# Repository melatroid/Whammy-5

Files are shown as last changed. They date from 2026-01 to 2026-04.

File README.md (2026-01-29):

# --Whammy 5 - NEO Mod--
This is a Modification for the Digitech Whammy 5- <br>
You get full Access to Midi Functions, with a Microcontroller inside. <br>
Im Working on nice Software for Whammy, that you can easly update. <br>
You need all modifications to use the featueres. Good Luck <br>

# Basic Version for Free
Software is for Free, to use all Features buy Pro Version

# Pro & Flashing Tool for 2040 Zero here...
<div align="left">
  <a href="https://www.nexosoft-engineering.de/neo/index.html">Pro Version & Flashing</a>
</div>

<h1>
!!! Attention !!!<br>
This Modification could brick your Device!
You lose your manufacturer's warranty.
<h1>

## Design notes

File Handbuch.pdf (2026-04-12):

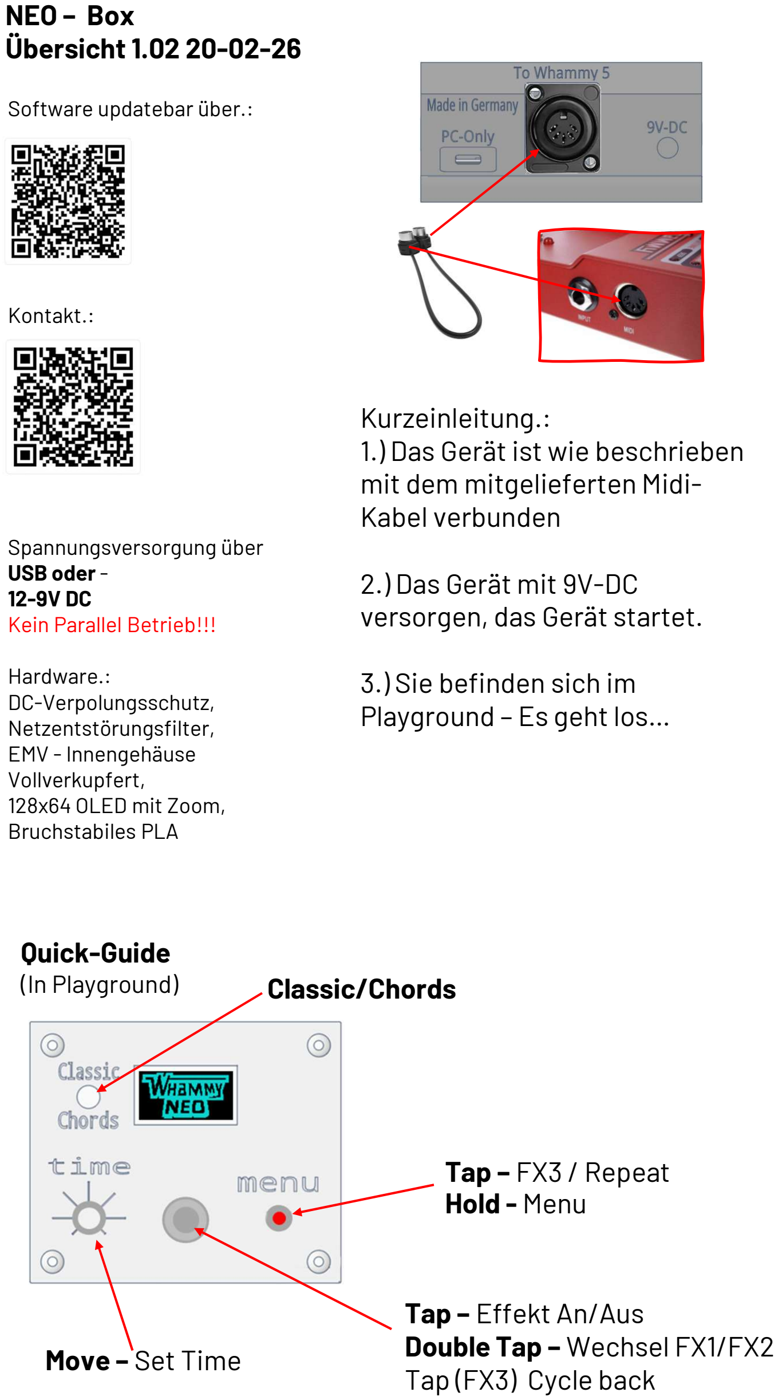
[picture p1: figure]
NEO – Box Übersicht 1.02 20-02-26; Software updatebar über.:; Kontakt.:; Spannungsversorgung über USB oder- 12-9V DC Kein Parallel Betrieb!!!; Hardware.: DC-Verpolungsschutz, Netzentstörungsfilter, EMV - Innengehäuse Vollverkupfert, 128x64 OLED mit Zoom, Bruchstabiles PLA; Quick-Guide (In Playground); Tap – Effekt An/Aus Double Tap – Wechsel FX1/FX2 Tap (FX3) Cycle back; Tap – FX3 / Repeat Hold - Menu; Classic/Chords; Move – Set Time; Kurzeinleitung.: 1.) Das Gerät ist wie beschrieben mit dem mitgelieferten Midi- Kabel verbunden; 2.) Das Gerät mit 9V-DC versorgen, das Gerät startet.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

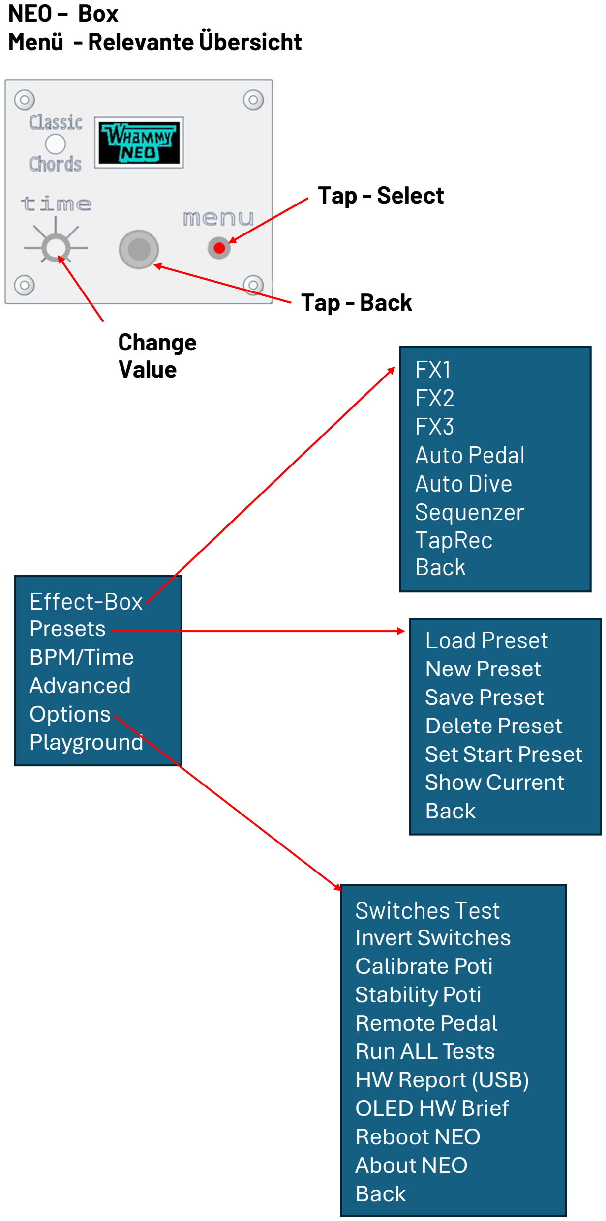
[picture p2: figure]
Menü - Relevante Übersicht; Effect-Box Presets BPM/Time Advanced Options Playground; Tap - Select; Switches Test Invert Switches Calibrate Poti Stability Poti Remote Pedal Run ALL Tests HW Report (USB) OLED HW Brief Reboot NEO About NEO Back; Load Preset New Preset Save Preset Delete Preset Set Start Preset Show Current Back; Tap - Back; FX1 FX2 FX3 Auto Pedal Auto Dive Sequenzer TapRec Back; Change Value

Effekt-Box

FX1
FX2
FX3

Auto Pedal
Auto Dive
Sequenzer
TapRec
Back

Festlegen von FX 1, FX2 und FX3

Grafikeditoren für Kurven etc.
Auch hier nach dem editieren speichern!

Zum Festlegen der FX1–3 sind Angaben zum gewünschten Effekt nötig. Diesen Effekt kennen Sie in der Regel bereits im Vorfeld, da Sie offensichtlich Besitzer und Spieler eines Whammy 5 sind. Man kann Gitarristen an dieser Stelle vorwerfen, dass sie ihren Lieblingseffekt schon länger haben und ihn nur weiter aufpeppen wollen. Falls dem nicht so ist, sollten Sie sich darum bemühen, eine klare Vorstellung davon zu entwickeln, wie es klingen soll.
Sie werden mit der NEO-Box nicht glücklich, wenn Sie sie als Findungswerkzeug für gute Sounds benutzen wollen. Umso nützlicher ist sie, wenn Sie bereits eine Vorstellung davon haben, wie es klingen soll.
Es wird in die linke und rechte Effektsektion des Whammy 5 unterteilt: Harmony- und Whammy-Effekte. Hier muss zunächst das grundlegende Verhalten eingestellt werden. Grundsätzlich ist der FX3 der Taste L (menu) vorbehalten. Sie ist für die Auto-Pedal-Funktionen vorgesehen, die ausgewählt und anschließend im entsprechenden Editor grafisch bearbeitet werden können.

Nach dem editieren unbedingt das Preset (Save Preset) überschrieben!

FX-Menü (FX 1 / FX 2 / FX 3) • | Type – Classic oder Chords • | Name/Mode – Whammy oder Harmony • | Behavior – Original - Momentary - Time Holding - Shutter Gate - Step Sequenzer - Tap Rec. • | Pedal Position (nur FX1/FX2)-

Whammy – ▲ 2 OCT - ▲ OCT - ▲ 5TH - ▲ 4TH - ▼ 2ND - ▼ 4TH - ▼ 5TH - ▼ OCT - ▼ 2 OCT

Harmony – 2ND/3RD - b3RD/3RD - 3RD/4TH - 4TH/5TH - 5TH/6TH - 5TH/7TH - 4TH/3RD - 5TH/4TH -

▲OCT/OCT▼

Grafik Editoren

FX1
FX2
FX3

Auto Pedal
Auto Dive
Sequenzer
TapRec
Back

Über die Effekt-Box sind die Editoren zugänglich. Dieses Skript soll nur eine kurze Einführung geben.

Wenn Sie sich in bereits in einem der Editoren befinden, kommen Sie über hold der L-Taste in das Menu des jeweiligen Editors.

M-Taste

Pedal und Dive bieten Rekord Funktionen mit der Pedal-Kurven über das Potentiometer geschrieben werden können. (DAW-Benutzer kennen
diesen Mechanismus des Schreibens und Veränderns von Musikdaten bereits)
Die aufgenommene Kurve kann, wie bei einem grafischen Equalizer verändert werden, wobei die Glockenbreite über L eingestellt wird. Es gibt hier eine umfangreiche Spielwiese an Tools im Menu, um zu experimentieren.

Bei TapRec wird die Tastensequenz von M aufgenommen. Sequenzer bildet die Ausnahme, dafür können hier Steps komfortabel über T gebaut werden und mit dem Poti auf die gewünschte Position gesetzt werden.

Die Editoren bieten eine Save Funktion, die mehr ermöglicht als die reinen Presets.

Einige Editoren haben in eingeschränkter Wiedergabe-Qualität, einen Play Modus, um die Bearbeitung direkt zu testen.

L-Taste – Select
Hold - Menu

Change
Value

Erklärungen
Presets legen das Startverhalten der NEO-Box für FX1/FX2/FX3 fest. NEO-Box speichert nicht automatisch, um Fehlerhafte-Änderungen über einen Neustart wiederrufbar zu machen. Das Start-preset ist Default

Advanced enthält Systemeigenschaften die direkte Auswirkungen, auf das Verhalten der Fußschalter hat.
Es wird wärmstens empfohlen nichts zu verändern. • AutoByp:ON|OFF (Auto-Bypass aktivieren/deaktivieren) • Delay: <0..30000>ms (Bypass-Delay) • TapHold: <20..60000>ms (Tap/Hold Zeit) • HoldMin: <50..60000>ms • HoldMax: <50..60000>ms • Smooth: <0..100> (Poti-Glättung) • Deb: <10..250>ms (Button Debounce) • Samp: <10..100>ms (Auto Sample) • Max: <5000..600000>ms (Auto MaxLen)
Options enthält Einstellungen, Kalibrierungen und Tests. • | Switches Test (Schaltertest) • | Invert Switches: (Untermenü zum Invertieren von Schaltern ) • | Calibrate Poti: (Potentiometer kalibrieren) • | Stability Poti: (Stabilitätstest Poti) • | Remote Pedal: (Remote-Pedal Test (AutoPedal/AutoDive)) • | Run ALL Tests: (Alle Tests ausführen ) • | HW Report (USB) (Hardware-Report via USB/Serial ausgeben ) • | OLED HW Brief: (OLED Kurzreport) • | Reboot NEO (Neustart) • | About NEO: Info-Screen
BPM/Time (Experimentell) • | Tap BPM- (BPM per Tap ermitteln) • | Set BPM- (BPM per Poti setzen) • | Show BPM- (aktuellen BPM-Wert ) • | Reset- (120 BPM)

NEO – FAQ • Beim Deaktivieren des Effekts, wird der

darunterliegende aktiv gesetzt, stimmt das?

Ja, Es ist von DT technisch so umgesetzt. Und nicht anders möglich • Es kommt zu ungleichmäßigen Schaltverhalten im

ShutterGate, TapRec, Sequenzer

Das Gerät zuvor im Modus länger laufen lassen, es stabilisiert sich. Zuvor Speichern, alles neustarten. • Das Gerät fordert mich auf einen Code einzugeben.

Kontakt über E-Mail herstellen. • Das Whammy schaltet/klickt laut.

Beim Wh5 hat DT -Relais verbaut, die als TrueBypass dienen. Relais sind mechanische Bauteile und unterliegen einer natürlichen Haltbarkeit. Schaltvorgänge nicht strapazieren. • Das Gerät geht nach Verbindung mit dem 9V Adapter

nicht an.

9V Spannungsversorgungen gibt es in zwei Ausführungen. Die NEO-Box wurde für die gängige Pedalboard 9DC ausgelegt.

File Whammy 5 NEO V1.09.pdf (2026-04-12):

Whammy 5 – NEO – Version 1.09 By melatroid

melatroid@gmail.com

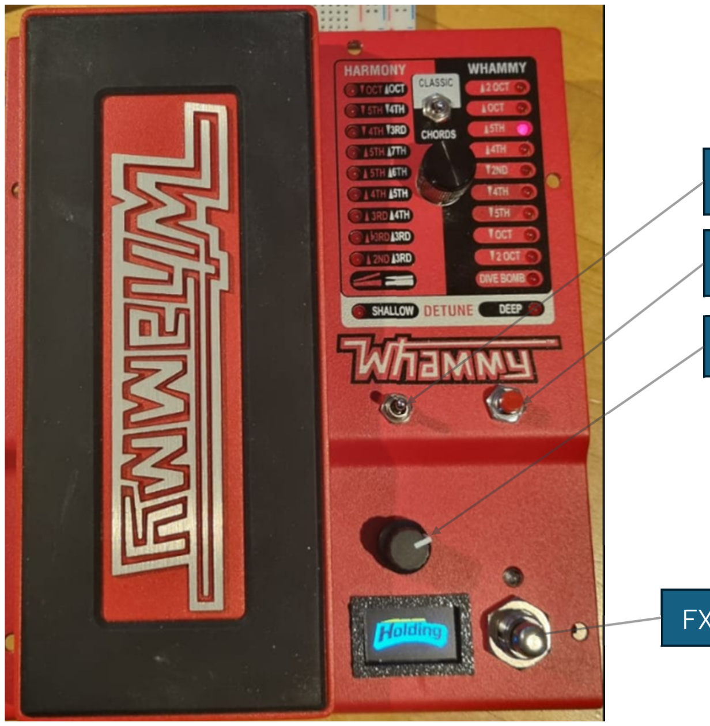
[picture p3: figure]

FX 1 - 2

Time/Position

FX 3 /
Menü

Calibration

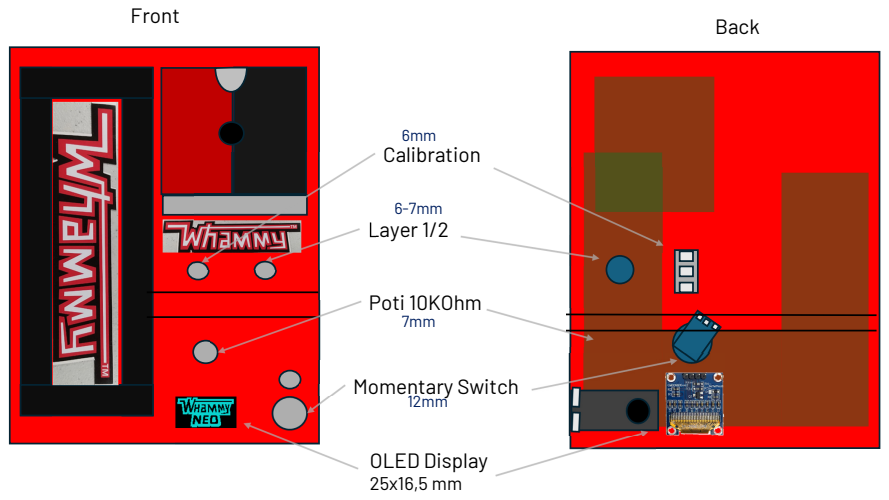
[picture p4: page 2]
Front; Back; Poti 10KOhm 7mm; Momentary Switch 12mm; Layer 1/2; OLED Display 25x16,5 mm; Calibration

### Drills

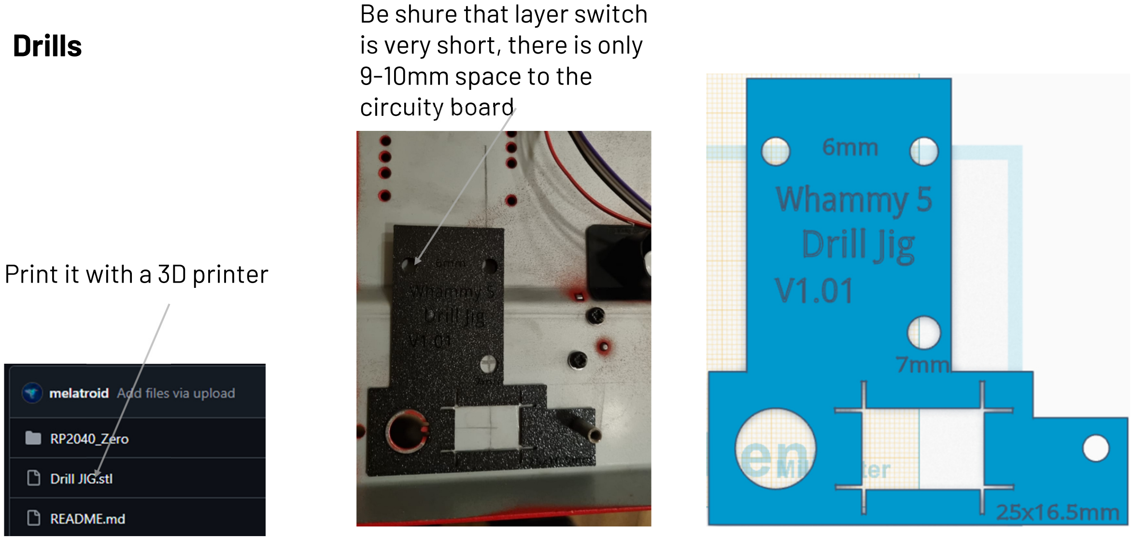
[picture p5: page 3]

Print it with a 3D printer

Be shure that layer switch is very short, there is only 9-10mm space to the
circuity board

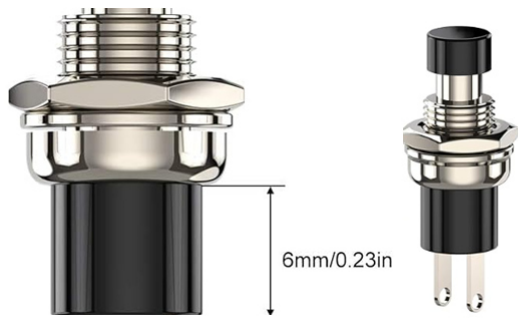
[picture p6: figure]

ELKO/Ceramic
Condenser

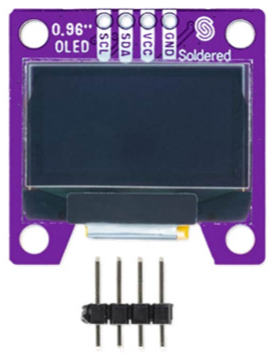
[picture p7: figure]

Raspberry Pi
2040 Zero

10KΩ

SPST, NO,
Momentary !!!

### Parts

220Ω 2x

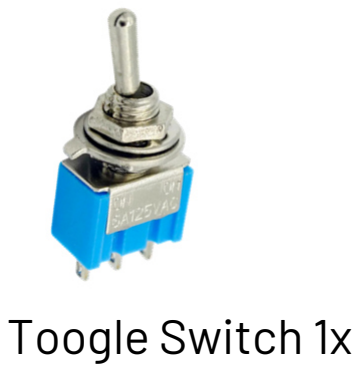
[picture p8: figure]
Toogle Switch 1x

Calibration (3 Way)

DC/DC
LM2596

uF

### 47 nF

B0505S-1W

https://tweakable-parts.com/en/footswitches/175-spst-momentary-switch.html
Normally Open! → PBS 24B 4L
Long Version!

SSD1306 OR
SSD1315
O-LED
I²C !!!

!!!
SPST, NO, 1x
Layer 1/2 Momentary !!!

### Tools

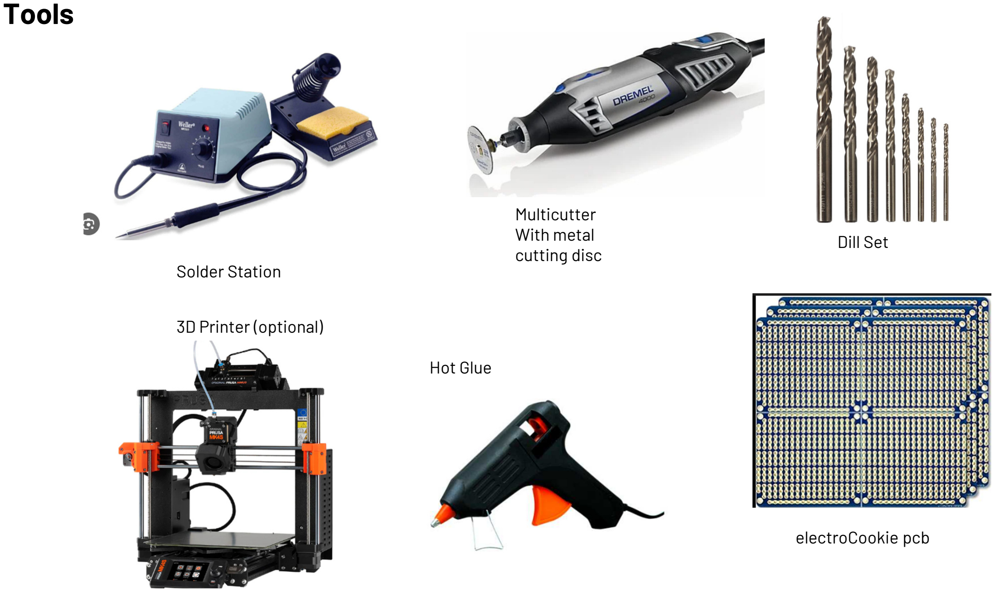
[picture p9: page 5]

Solder Station

Multicutter
With metal
cutting disc

Dill Set

3D Printer (optional)

Hot Glue

electroCookie pcb

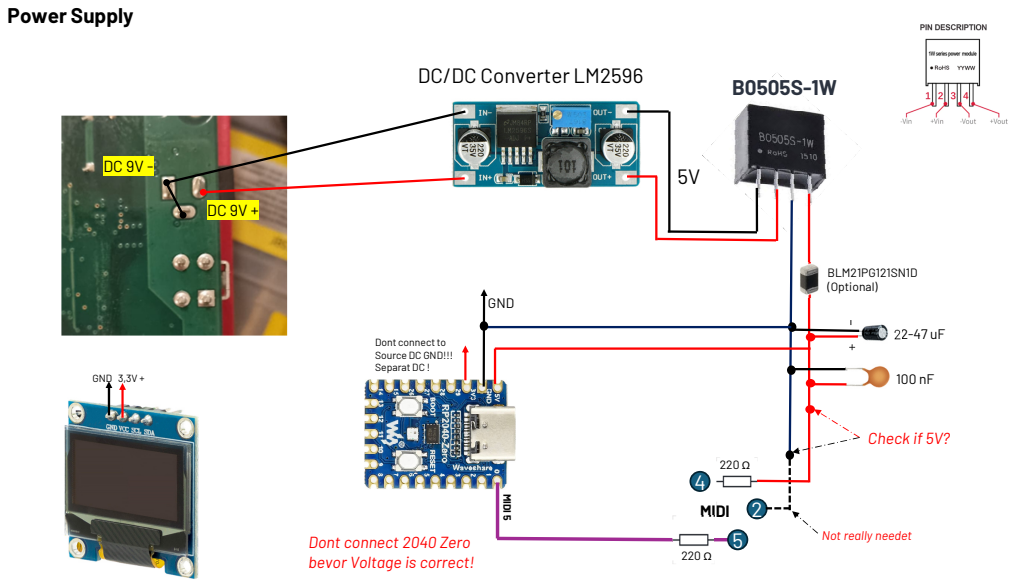
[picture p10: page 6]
Power Supply; MIDI 5; MIDI; BLM21PG121SN1D (Optional); Check if 5V?; 3,3V +GND; GND

DC/DC Converter LM2596

Dont connect to
Source DC GND!!!
Separat DC !

Not really needet

Dont connect 2040 Zero
bevor Voltage is correct!

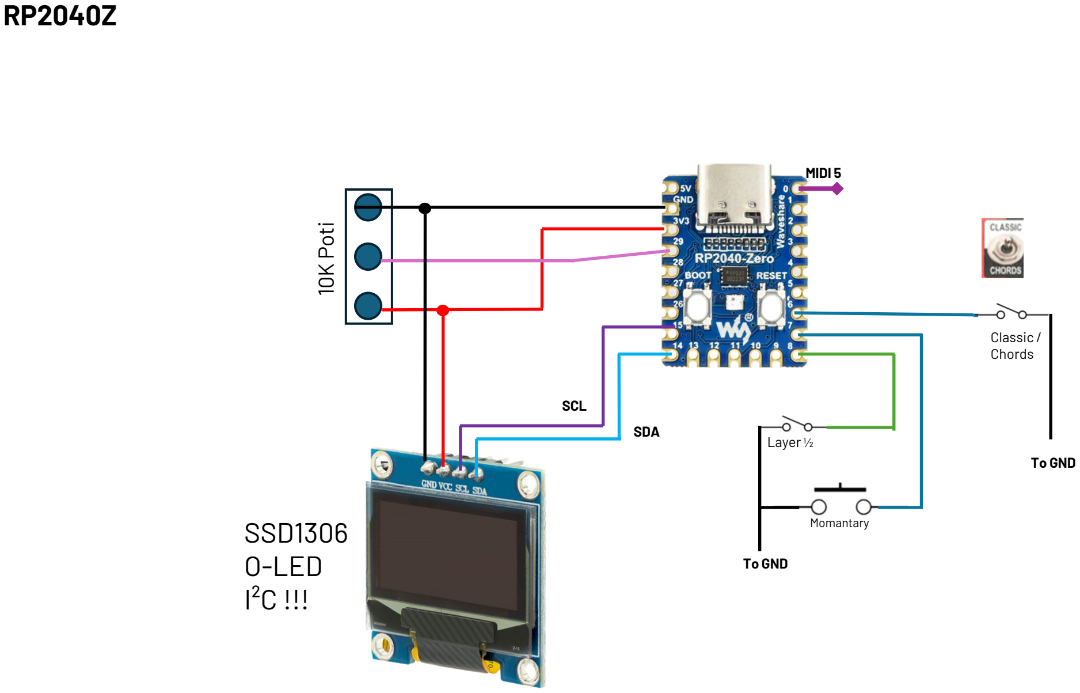
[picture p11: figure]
10K Poti; Momantary; MIDI 5; Layer ½; SDA; SCL; SSD1306 O-LED I²C !!!; To GND; Classic / Chords

### Inside

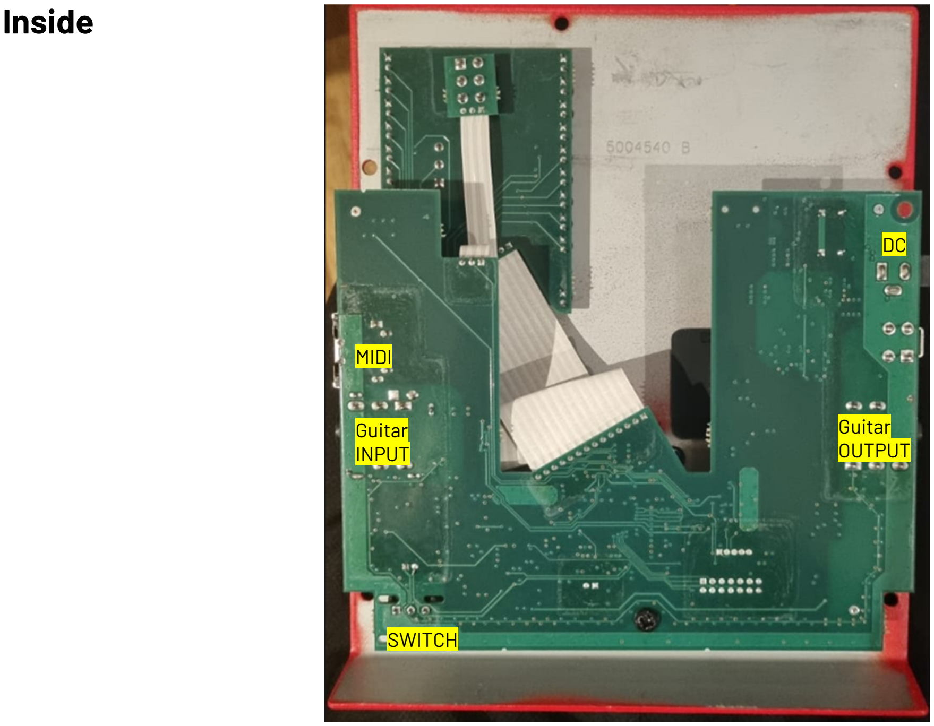
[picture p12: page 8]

Guitar
INPUT

Guitar
OUTPUT

DC

MIDI

SWITCH

### Midi

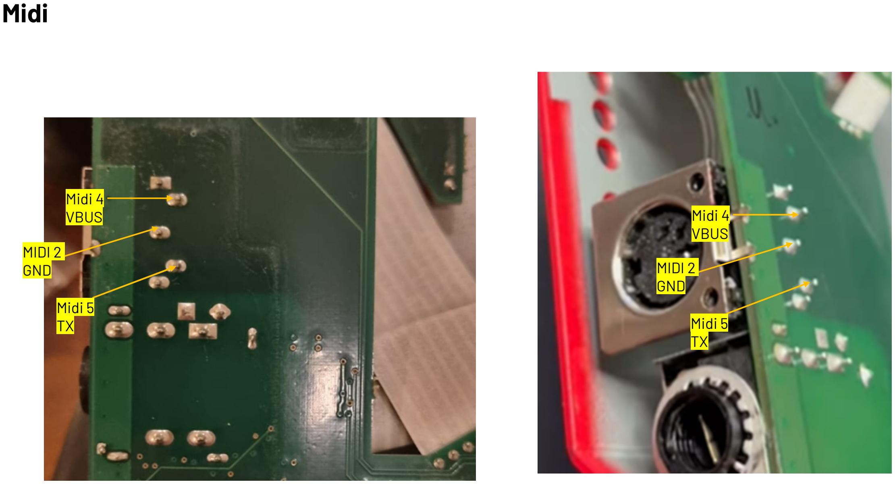
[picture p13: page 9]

Midi 4
VBUS

Midi 5
TX

MIDI 2
GND

Midi 4
VBUS

Midi 5
TX

MIDI 2
GND

### Circuit Bord

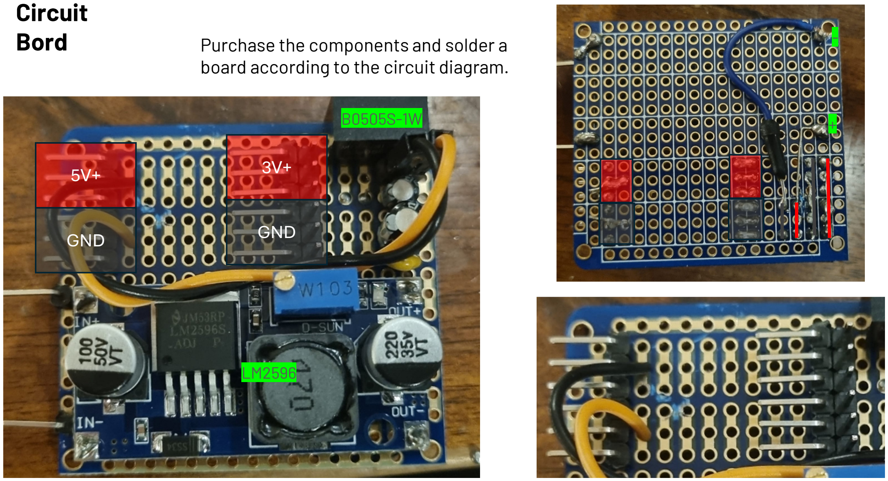
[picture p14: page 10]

B0505S-1W

LM2596

3V+

GND GND

5V+

+- Purchase the components and solder a board according to the circuit diagram.

### Test Circuit Board

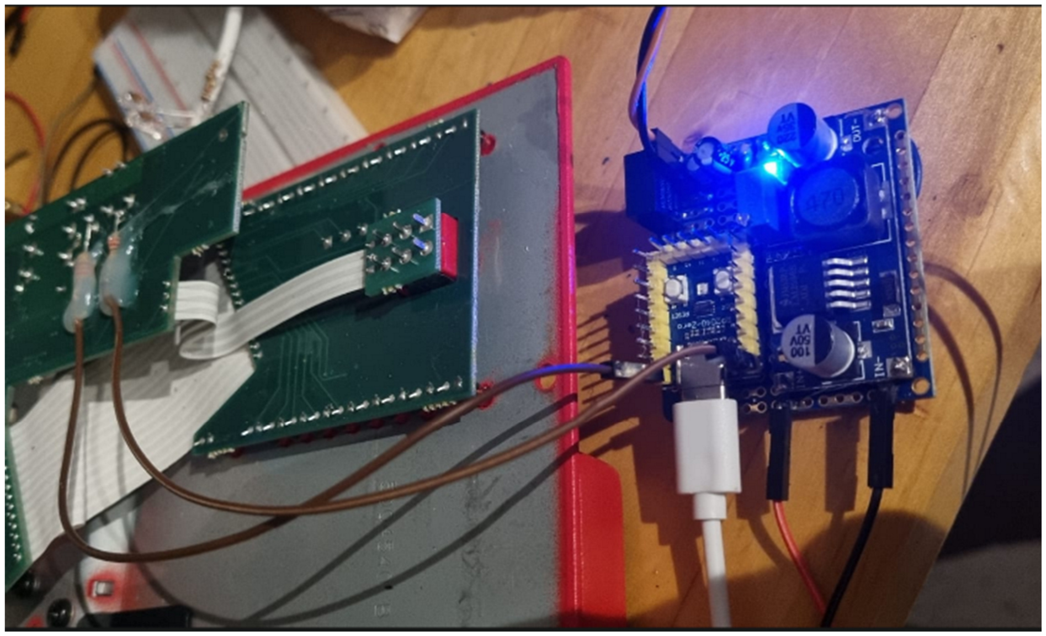
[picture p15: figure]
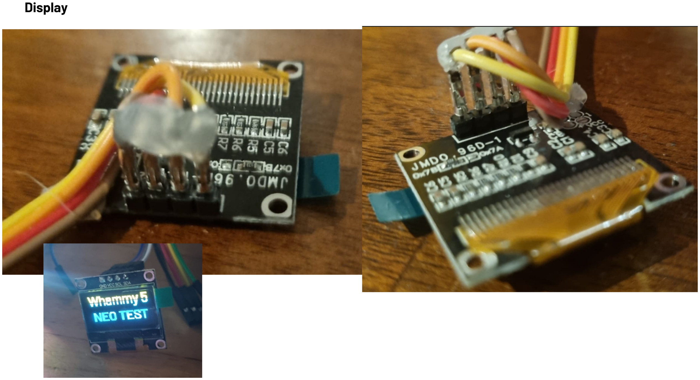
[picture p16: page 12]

Display

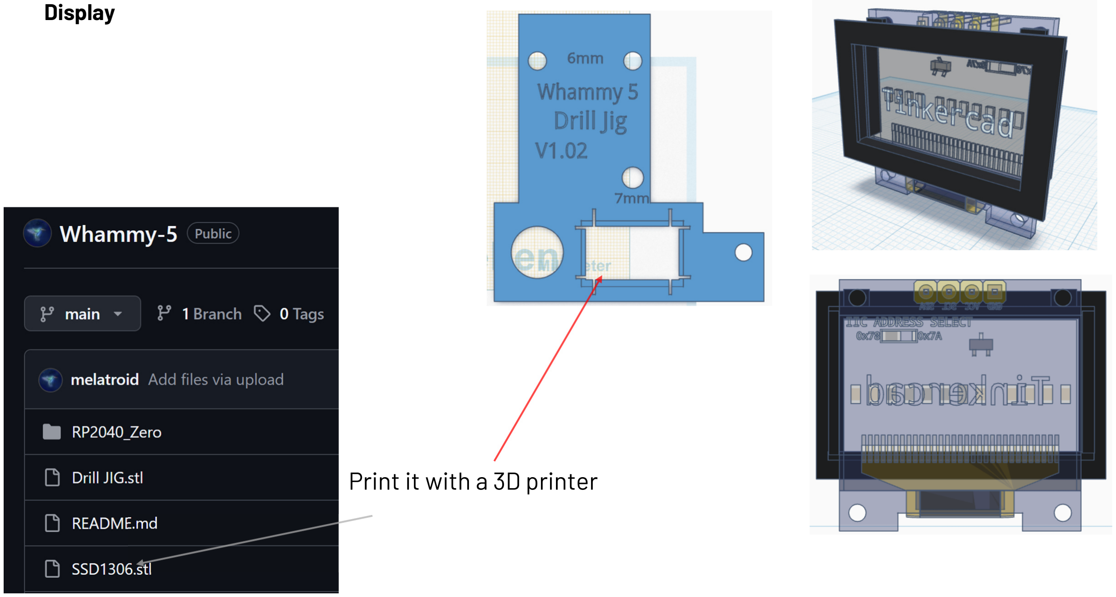
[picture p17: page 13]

Display

Print it with a 3D printer

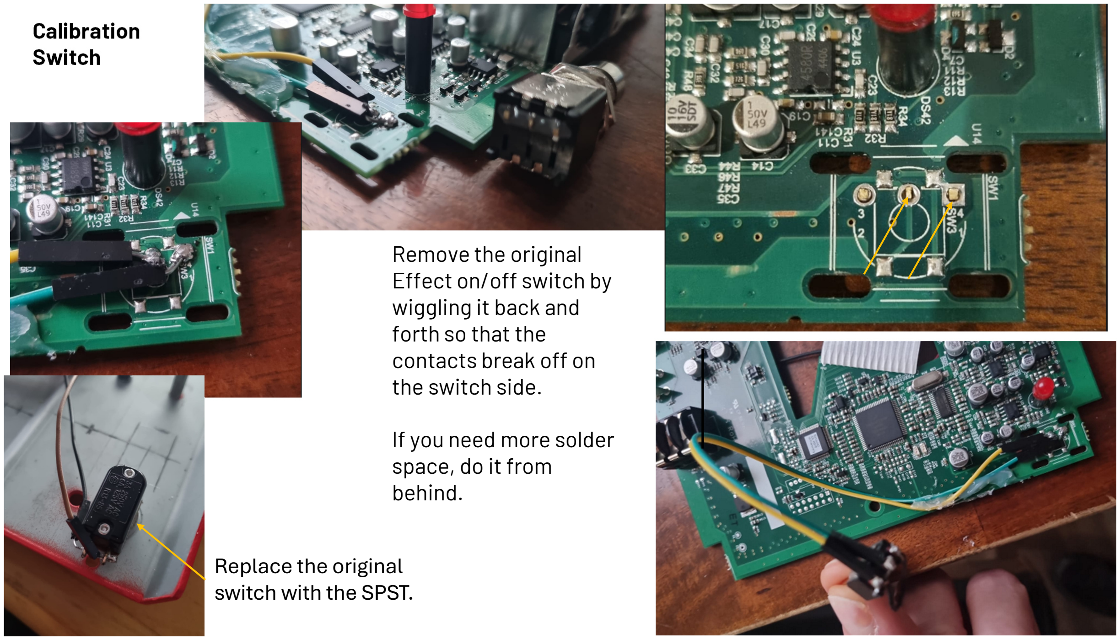
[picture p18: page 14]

Calibration
Switch

Remove the original
Effect on/off switch by
wiggling it back and
forth so that the
contacts break off on
the switch side.

If you need more solder
space, do it from
behind.

Replace the original
switch with the SPST.

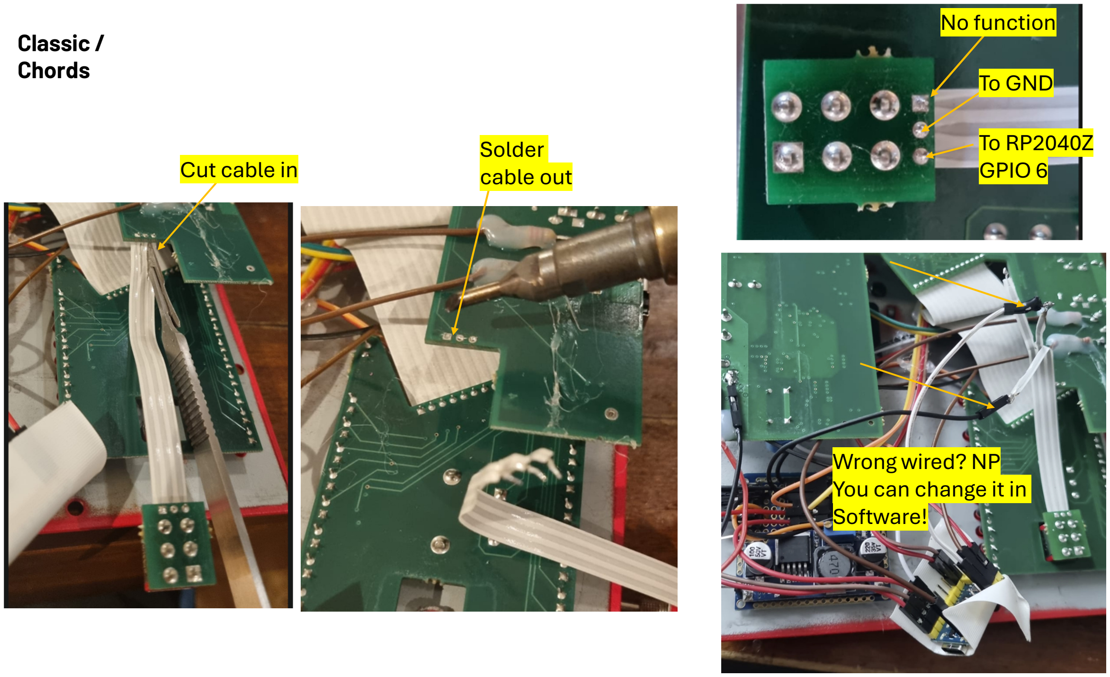
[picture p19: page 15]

Classic /
Chords

No function

To GND

To RP2040Z
Cut cable in | GPIO 6

Solder
cable out

Wrong wired? NP
You can change it in
Software!

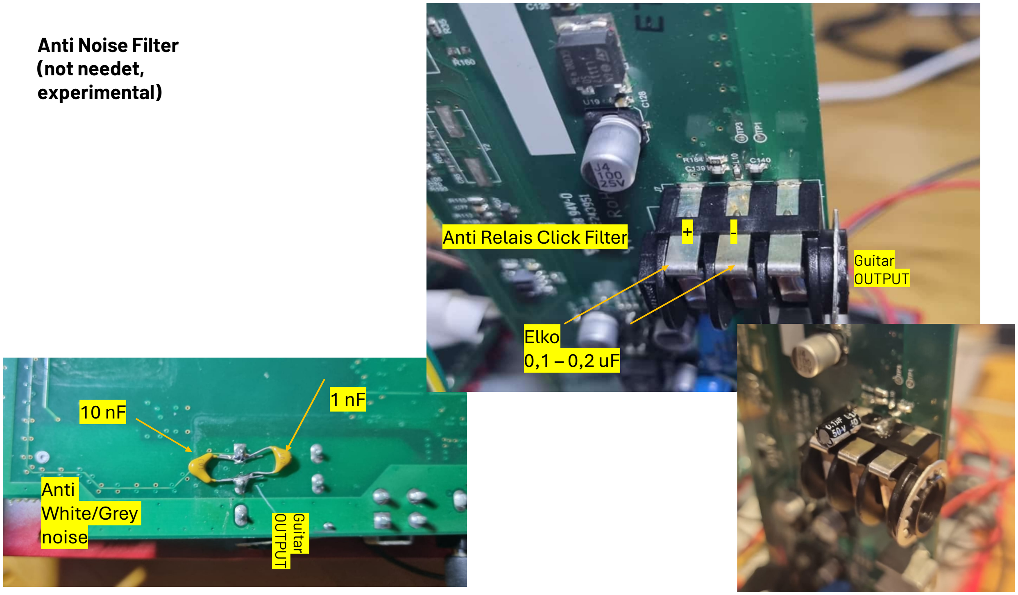
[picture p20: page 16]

Anti Noise Filter
(not needet,
experimental)

OUTPUT

Guitar

### 1 nF 10 nF

Anti
White/Grey
noise

Anti Relais Click Filter

Elko
0,1 – 0,2 uF
+ | - | Guitar
| | OUTPUT

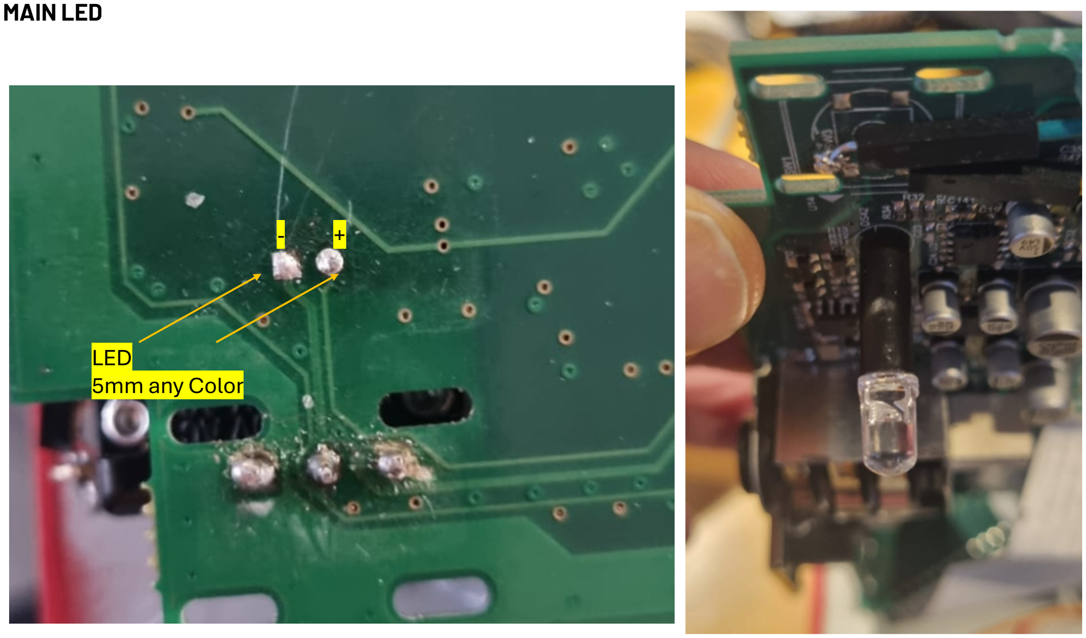
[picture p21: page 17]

MAIN LED

LED

5mm any Color | - | +

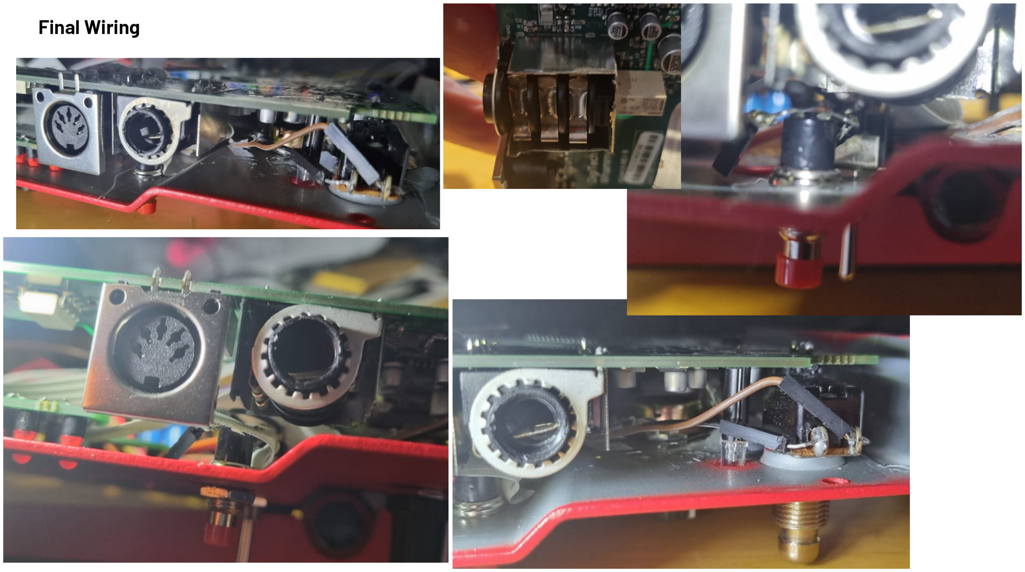
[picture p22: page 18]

Final Wiring

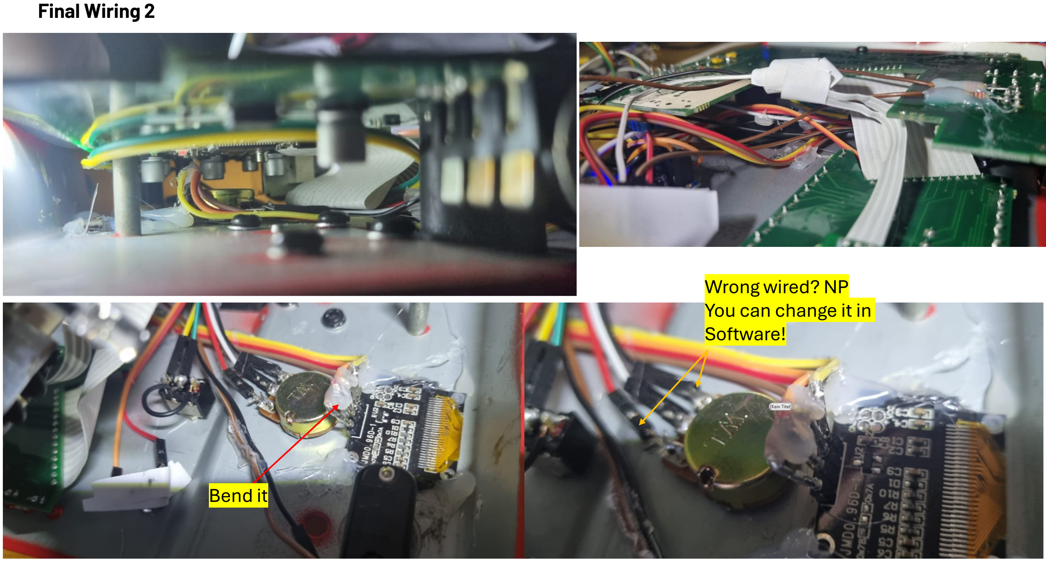
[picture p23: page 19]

Final Wiring 2

Wrong wired? NP
You can change it in
Software!

Bend it

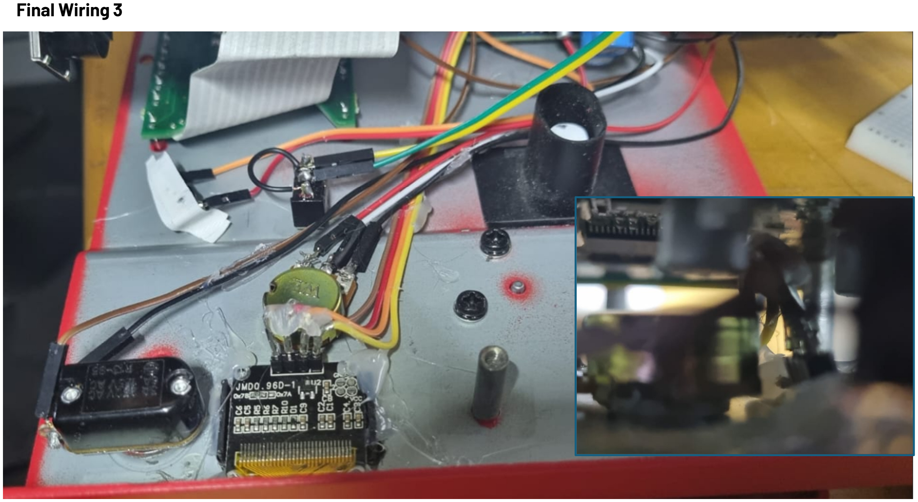
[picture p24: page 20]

Final Wiring 3

Auto Pedal Return


1,12kg

Software for
RP2040 Zero

2.) Download Pro

Flashing Tool https://www.nexosoft-engineering.de/neo/index.html

3.) Buy Software

4.) Flash to 2040 Zero

5.) ROCK

1.)
Download the
Testsuite and
flash it with Thonny
IDE to RP2040

All wiring is fine?

Got to ->

DONT CONNECT
RP2040 TO PC
WHILE 9V DC IS
CONNECTET

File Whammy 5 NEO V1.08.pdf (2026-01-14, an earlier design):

Whammy 5 – NEO – Version 1.08 By melatroid

melatroid@gmail.com


FX 1 - 2

Time/Position

FX 3 /
Menü

Calibration

Front; Back; Poti 10KOhm 7mm; Momentary Switch 12mm; Layer 1/2; OLED Display 25x16,5 mm; Calibration

## Drills


Print it with a 3D printer

Be shure that layer switch is very short, there is only 9-10mm space to the
circuity board


ELKO/Ceramic
Condenser


Raspberry Pi
2040 Zero

10KΩ

SPST, NO,
Momentary !!!

## Parts

220Ω 2x

Toogle Switch 1x

Calibration (3 Way)

DC/DC
LM2596

uF

### 47 nF

B0505S-1W

https://tweakable-parts.com/en/footswitches/175-spst-momentary-switch.html
Normally Open! PBS 24B 4L
Long Version!

SSD1306 OR
SSD1315
O-LED
I²C !!!

!!!
SPST, NO, 1x
Layer 1/2 Momentary !!!

## Tools


Solder Station

Multicutter
With metal
cutting disc

Dill Set

3D Printer (optional)

Hot Glue

electroCookie pcb

Power Supply; 5V MIDI 5; MIDI; BLM21PG121SN1D (Optional); Check if 5V?; GND 3,3V +; GND

DC/DC Converter LM2596

Dont connect to
Source DC GND!!!
Separat DC !

Dont connect 2040 Zero
bevor Voltage is correct!

Not really needet

10K Poti; Momantary; MIDI 5; Layer ½; SDA; SCL; SSD1306 O-LED I²C !!!; To GND; Classic / Chords

## Inside


Guitar
INPUT

Guitar
OUTPUT

DC

MIDI

SWITCH

## Midi


Midi 4
VBUS

Midi 5
TX

MIDI 2
GND

Midi 4
VBUS

Midi 5
TX

MIDI 2
GND

Circuit board according to the circuit diagram.

## Bord


B0505S-1W

LM2596

3V+

GND GND

5V+

+

- Purchase the components and solder a

## Test Circuit Board


Display


Display

Print it with a 3D printer


Calibration
Switch

Remove the original
Effect on/off switch by
wiggling it back and
forth so that the
contacts break off on
the switch side.

If you need more solder
space, do it from
behind.

Replace the original
switch with the SPST.


Classic /
Chords

No function

To GND

To RP2040Z
Cut cable in | GPIO 6

Solder
cable out

Wrong wired? NP
You can change it in
Software!


Anti Noise Filter
(not needet,
experimental) | OUTPUT Guitar

### 1 nF 10 nF

Anti
White/Grey
noise

Anti Relais Click Filter

Elko
0,1 – 0,2 uF

+ -
Guitar
OUTPUT


MAIN LED

LED
5mm any Color
- +


Final Wiring


Final Wiring 2

Wrong wired? NP
You can change it in
Software!

Bend it


Final Wiring 3

Auto Pedal Return


1,12kg

Software for
RP2040 Zero

2.) Download Pro

Flashing Tool https://www.nexosoft-engineering.de/neo/index.html

3.) Buy Software

4.) Flash to 2040 Zero

5.) ROCK

1.)
Download the
Testsuite and
flash it with Thonny
IDE to RP2040

All wiring is fine?

Got to ->

DONT CONNECT
RP2040 TO PC
WHILE 9V DC IS
CONNECTET

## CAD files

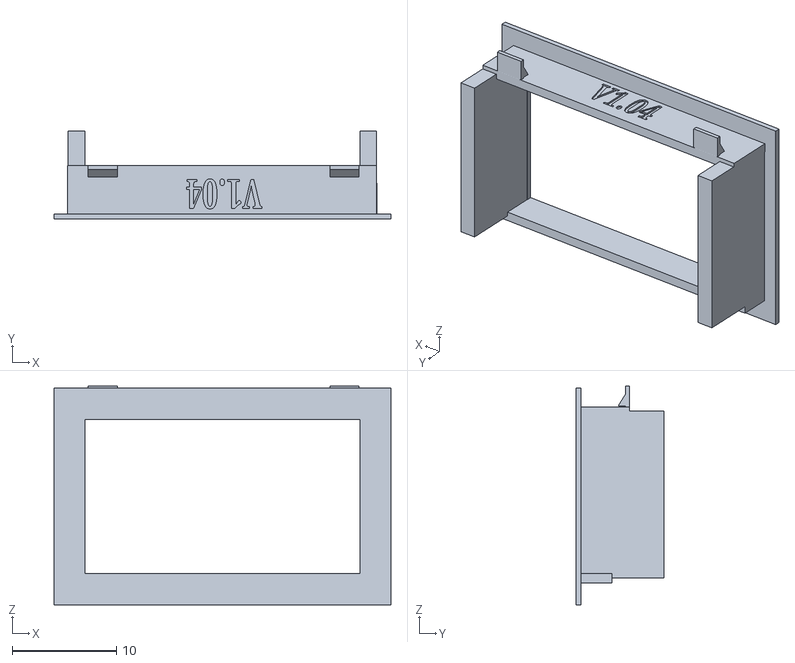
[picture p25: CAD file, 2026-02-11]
SSD1306_Back.stl
32.3 x 8.45 x 21.0

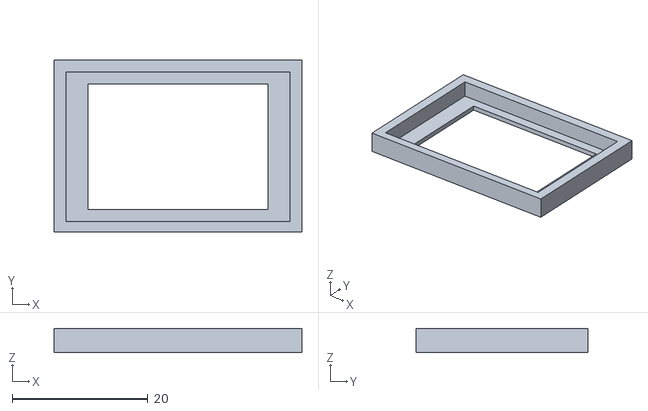
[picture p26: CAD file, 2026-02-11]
SSD1306_Front.stl
36.5 x 25.2 x 3.60

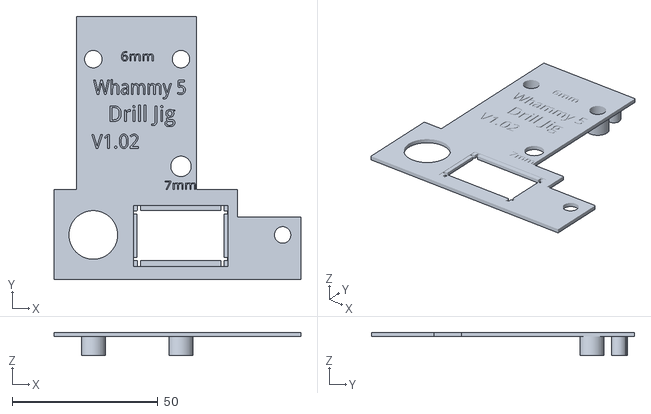
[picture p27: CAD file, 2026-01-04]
Drill JIG.stl
84.8 x 90.4 x 8.00

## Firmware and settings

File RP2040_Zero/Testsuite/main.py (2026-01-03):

# Melatroid - Whammy 5 MIDI TEST SUITE - 1.05
#
# COPY ALL PY FILES TO RP2040!!!
#
PIN_FOOTSW = 7
PIN_LAYER_SWITCH = 8
PIN_POT = 29
POT_DEADZONE_8BIT = 10
PIN_BANK_SWITCH = 6
BANK_SWITCH_INVERT = True # Set to "False" it Classic and Chords Toogle is wrong invertet

OLED_I2C_ID = 1
OLED_SCL_PIN = 15
OLED_SDA_PIN = 14
OLED_W = 128
OLED_H = 64
OLED_FREQ = 400000
OLED_ADDR_FALLBACK = 0x3c

OLED_ENABLED = True

TEST_DIRECT_MIDI_SWITCH = True

from machine import Pin, ADC, UART, I2C
import time
import framebuf

try:
    import ui_menu
    UI_MENU_AVAILABLE = True
except ImportError:
    ui_menu = None
    UI_MENU_AVAILABLE = False
    print("[WARN] ui_menu.py not found -> menu disabled")

class TimeoutError(Exception):
    pass

def run_with_timeout(fn, timeout_ms, name="task", *args, **kwargs):
    t0 = time.ticks_ms()

    def timeout_cb():
        return time.ticks_diff(time.ticks_ms(), t0) >= timeout_ms

    try:
        return fn(timeout_cb, *args, **kwargs)
    except TypeError:
        if timeout_cb():
            raise TimeoutError(f"{name} timeout before start")
        return fn(*args, **kwargs)

try:
    import ssd1306
    SSD1306_AVAILABLE = True
except ImportError:
    ssd1306 = None
    SSD1306_AVAILABLE = False
    print("[WARN] ssd1306.py not found -> OLED disabled")

try:
    import display_ui
    DISPLAY_UI_AVAILABLE = True
except ImportError:
    display_ui = None
    DISPLAY_UI_AVAILABLE = False
    print("[WARN] display_ui.py not found -> UI helper disabled")

try:
    from pictures import START, START_W, START_H
    PICTURES_AVAILABLE = True
except ImportError:
    START = None
    START_W = 128
    START_H = 64
    PICTURES_AVAILABLE = False
    print("[WARN] pictures.py not found -> start image disabled")

try:
    from animation import ANI1, ANI1_W, ANI1_H
    ANIMATION_AVAILABLE = True
except ImportError:
    ANI1 = None
    ANI1_W = 128
    ANI1_H = 64
    ANIMATION_AVAILABLE = False
    print("[WARN] animation.py not found -> start animation disabled")

if ANIMATION_AVAILABLE and (ANI1 is not None):
    fb = (ANI1_W * ((ANI1_H + 7)//8))
    try:
        n = len(ANI1)
        frames = (n // fb) if (fb > 0 and n % fb == 0) else "??"
        print("[ANI] bytes:", n, "frame_bytes:", fb, "frames:", frames)
    except Exception as e:
        print("[ANI] check failed:", e)

HW_STATUS = {
    "OLED":   {"ok": False, "weight": 35, "info": ""},
    "MIDI":   {"ok": False, "weight": 40, "info": ""},
    "INPUTS": {"ok": False, "weight": 25, "info": ""},
}

def hw_score_percent():
    return sum(v["weight"] for v in HW_STATUS.values() if v["ok"])

def print_hw_report():
    print("\n=== HARDWARE HEALTH REPORT ===")
    for name, v in HW_STATUS.items():
        state = "OK" if v["ok"] else "FAIL"
        print(f"{name:<7}: {state:<4} ({v['weight']:>2}%) - {v['info']}")
    print(f"\nTOTAL HARDWARE FUNCTIONALITY: {hw_score_percent()} / 100 %")
    print("=== END HARDWARE REPORT ===\n")

def oled_hw_report_brief():
    if not oled:
        return
    ok = hw_score_percent()
    oled.fill(0)
    oled.text("HW REPORT", 0, 0)
    oled.text(f"SCORE: {ok:3d}%", 0, 12)
    oled.text(f"OLED:{'OK' if HW_STATUS['OLED']['ok'] else 'NO'}", 0, 24)
    oled.text(f"MIDI:{'OK' if HW_STATUS['MIDI']['ok'] else 'NO'}", 0, 34)
    oled.text(f"IN  :{'OK' if HW_STATUS['INPUTS']['ok'] else 'NO'}", 0, 44)
    oled.show()
    time.sleep_ms(1200)

MIDI_ENABLED = True
MIDI_UART_ID = 0
MIDI_BAUD = 31250
MIDI_TX_PIN = 0

TEST_CHANNEL = 0
PC_MINUS_ONE = False

PC_STEP_DELAY_MS = 100
EFFECT_OFF_DELAY_MS = 100
BETWEEN_MODES_MS = 100

SEND_EFFECT_OFF_AFTER_ACTIVE = True

DEBOUNCE_MS = 30
POLL_MS = 5
PRINT_EVERY_MS = 1000

POT_SMOOTH_ALPHA_NUM = 1
POT_SMOOTH_ALPHA_DEN = 8
POT_PRINT_THRESHOLD_8BIT = 3

LIVE_SEND_CC11 = True

LIVE_CH_CLASSIC = TEST_CHANNEL
LIVE_CH_CHORDS  = TEST_CHANNEL

MENU_OPEN_HOLD_MS = 900

DETUNE_NAMES = ["SHALLOW", "DEEP"]

WHAMMY_NAMES = [
    "▲ 2 OCT",
    "▲ OCT",
    "▲ 5TH",
    "▲ 4TH",
    "▼ 2ND",
    "▼ 4TH",
    "▼ 5TH",
    "▼ OCT",
    "▼ 2 OCT",
    "DIVE BOMB",
]

HARMONY_NAMES = [
    "2ND/3RD",
    "b3RD/3RD",
    "3RD/4TH",
    "4TH/5TH",
    "5TH/6TH",
    "5TH/7TH",
    "4TH/3RD",
    "5TH/4TH",
    "▲OCT/OCT▼",
]

footsw = Pin(PIN_FOOTSW, Pin.IN, Pin.PULL_UP)
layer_sw = Pin(PIN_LAYER_SWITCH, Pin.IN, Pin.PULL_UP)
bank_sw = Pin(PIN_BANK_SWITCH, Pin.IN, Pin.PULL_UP)

pot = ADC(Pin(PIN_POT))

try:
    _ = footsw.value()
    _ = layer_sw.value()
    _ = bank_sw.value()
    _ = pot.read_u16()
    HW_STATUS["INPUTS"]["ok"] = True
    HW_STATUS["INPUTS"]["info"] = "footsw + layer + bank pin + pot OK"
except Exception as e:
    HW_STATUS["INPUTS"]["info"] = str(e)

midi = None
if MIDI_ENABLED:
    try:
        midi = UART(MIDI_UART_ID, baudrate=MIDI_BAUD, tx=Pin(MIDI_TX_PIN))
        HW_STATUS["MIDI"]["ok"] = True
        HW_STATUS["MIDI"]["info"] = f"UART{MIDI_UART_ID} TX GP{MIDI_TX_PIN} OK"
    except Exception as e:
        midi = None
        HW_STATUS["MIDI"]["info"] = f"init failed: {e}"
else:
    HW_STATUS["MIDI"]["info"] = "disabled"

def midi_write(data: bytes):
    if MIDI_ENABLED and midi is not None:
        midi.write(data)

def midi_cc(cc, val, ch0):
    midi_write(bytes([0xB0 | (ch0 & 0x0F), cc & 0x7F, val & 0x7F]))

def midi_pc(pc, ch0):
    send_pc = (pc - 1) if PC_MINUS_ONE else pc
    if send_pc < 0:
        send_pc = 0
    midi_write(bytes([0xC0 | (ch0 & 0x0F), send_pc & 0x7F]))

def midi_heartbeat():
    if not (MIDI_ENABLED and midi is not None):
        print("[MIDI] Heartbeat skipped (MIDI not available).")
        return
    try:
        midi_pc(0, TEST_CHANNEL)
        time.sleep_ms(20)
        midi_cc(11, 64, TEST_CHANNEL)
        print("[MIDI] Heartbeat sent (PC0 + CC11=64).")
    except Exception as e:
        print("[MIDI] Heartbeat failed:", e)


def oled_show_picture(image_name=None, ms=200):
    if not oled:
        return
    try:
        import pictures
        name = None
        if image_name and hasattr(pictures, image_name):
            name = image_name
        elif hasattr(pictures, "START"):
            name = "START"
        if not name:
            return
        data = getattr(pictures, name)
        w = getattr(pictures, f"{name}_W", getattr(pictures, "START_W", OLED_W))
        h = getattr(pictures, f"{name}_H", getattr(pictures, "START_H", OLED_H))
        buf = bytearray(data)
        fb0 = framebuf.FrameBuffer(buf, w, h, framebuf.MONO_VLSB)
        oled.fill(0)
        oled.blit(fb0, 0, 0)
        oled.show()
        time.sleep_ms(ms)
    except:
        pass

def boot_splash():
    if not oled:
        print("[BOOT] no oled -> skip splash")
        return

    print("[BOOT] PICTURES_AVAILABLE:", PICTURES_AVAILABLE, "START is None:", START is None)
    print("[BOOT] ANIMATION_AVAILABLE:", ANIMATION_AVAILABLE, "ANI1 is None:", ANI1 is None)

    if PICTURES_AVAILABLE and (START is not None):
        try:
            buf = bytearray(START)
            fb0 = framebuf.FrameBuffer(buf, START_W, START_H, framebuf.MONO_VLSB)
            oled.fill(0)
            oled.blit(fb0, 0, 0)
            oled.show()
            time.sleep_ms(1200)
        except Exception as e:
            print("[BOOT] start image failed:", e)

    if ANIMATION_AVAILABLE and (ANI1 is not None):
        try:
            oled_play_animation(oled, ANI1, w=ANI1_W, h=ANI1_H, fps=12, loop=False, clear=True)
            time.sleep_ms(200)
        except Exception as e:
            print("[BOOT] animation failed:", e)

DBG_COL_MODE = 8
DBG_COL_STATE = 7
DBG_COL_PC = 4
DBG_COL_CH = 3
DBG_COL_NAME = 28

def fmt_dbg(mode, state, pc, ch1, name):
    mode_s = f"{str(mode):<{DBG_COL_MODE}}"
    state_s = f"{str(state):<{DBG_COL_STATE}}"
    pc_s = f"{int(pc):>{DBG_COL_PC}d}"
    ch_s = f"{int(ch1):>{DBG_COL_CH}d}"
    name_s = f"{str(name):<{DBG_COL_NAME}}"
    return f"{mode_s} {state_s} PC:{pc_s} CH:{ch_s} {name_s}"

def print_dbg_header(ch1):
    print(fmt_dbg("MODE", "STATE", 0, ch1, "NAME"))
    print("-" * (DBG_COL_MODE + DBG_COL_STATE + DBG_COL_PC + DBG_COL_CH + DBG_COL_NAME + 12))

def print_pin_assignments():
    print("\n=== PIN ASSIGNMENTS / CONFIG ===")
    print(f"MOMANTARY        : GP{PIN_FOOTSW} (IN, PULL_UP)")
    print(f"LAYER SWITCH     : GP{PIN_LAYER_SWITCH} (IN, PULL_UP)  [MENU HOLD]")
    print(f"BANK SWITCH      : GP{PIN_BANK_SWITCH} (IN, PULL_UP)  [to GND]")
    print(f"BANK INVERT      : {BANK_SWITCH_INVERT}")
    print(f"POT (ADC)        : GP{PIN_POT} (ADC)")

    if OLED_ENABLED:
        print("OLED             : ENABLED")
        print(f"  I2C ID          : {OLED_I2C_ID}")
        print(f"  SDA             : GP{OLED_SDA_PIN}")
        print(f"  SCL             : GP{OLED_SCL_PIN}")
        print(f"  RESOLUTION      : {OLED_W}x{OLED_H}")
        print(f"  I2C FREQ        : {OLED_FREQ}")
        print(f"  ADDR FALLBACK   : {hex(OLED_ADDR_FALLBACK)}")
    else:
        print("OLED             : DISABLED")

    if MIDI_ENABLED:
        print("MIDI             : ENABLED")
        print(f"  UART ID         : {MIDI_UART_ID}")
        print(f"  BAUD            : {MIDI_BAUD}")
        print(f"  TX              : GP{MIDI_TX_PIN} (TX only)")
        print(f"  TEST CHANNEL    : {TEST_CHANNEL} (CH shown as {TEST_CHANNEL+1})")
        print(f"  PC_MINUS_ONE    : {PC_MINUS_ONE}")
        print(f"  DIRECT_SWITCH   : {TEST_DIRECT_MIDI_SWITCH} (TEST mode: skip OFF)")
        print(f"  LIVE_CH_CLASSIC : {LIVE_CH_CLASSIC} (CH shown as {LIVE_CH_CLASSIC+1})")
        print(f"  LIVE_CH_CHORDS  : {LIVE_CH_CHORDS} (CH shown as {LIVE_CH_CHORDS+1})")
    else:
        print("MIDI             : DISABLED")

    print("=== END CONFIG ===\n")

oled = None
oled_addr = OLED_ADDR_FALLBACK

def _oled_init(timeout_cb=None):
    global oled, oled_addr

    if not (OLED_ENABLED and SSD1306_AVAILABLE and ssd1306 is not None):
        return

    if timeout_cb and timeout_cb():
        raise TimeoutError("OLED init timeout before start")

    i2c = I2C(OLED_I2C_ID, scl=Pin(OLED_SCL_PIN), sda=Pin(OLED_SDA_PIN), freq=OLED_FREQ)
    devices = i2c.scan()
    if not devices:
        raise RuntimeError("No I2C devices found")

    addr = None
    for preferred in (0x3C, 0x3D):
        if preferred in devices:
            addr = preferred
            break
    if addr is None:
        addr = devices[0]

    oled_addr = addr
    oled = ssd1306.SSD1306(OLED_W, OLED_H, i2c, addr=oled_addr)

try:
    if OLED_ENABLED and SSD1306_AVAILABLE and ssd1306 is not None:
        print("[OLED] init (fail-safe)...")
        run_with_timeout(_oled_init, 1200, "OLED init")
        if oled:
            HW_STATUS["OLED"]["ok"] = True
            HW_STATUS["OLED"]["info"] = f"I2C{OLED_I2C_ID} addr {hex(oled_addr)}"
        else:
            HW_STATUS["OLED"]["info"] = "not detected"
    else:
        if not OLED_ENABLED:
            HW_STATUS["OLED"]["info"] = "disabled"
        elif not SSD1306_AVAILABLE:
            HW_STATUS["OLED"]["info"] = "ssd1306.py missing"
        else:
            HW_STATUS["OLED"]["info"] = "not available"
except Exception as e:
    oled = None
    oled_addr = OLED_ADDR_FALLBACK
    HW_STATUS["OLED"]["ok"] = False
    HW_STATUS["OLED"]["info"] = f"init failed/timeout: {e}"
    print("[WARN] OLED init skipped:", e)

def oled_clear():
    if oled:
        oled.fill(0)
        oled.show()

_ARROW_UP_8 = bytes([
    0b00011000,
    0b00111100,
    0b01111110,
    0b00011000,
    0b00011000,
    0b00011000,
    0b00011000,
    0b00000000,
])

_ARROW_DN_8 = bytes([
    0b00011000,
    0b00011000,
    0b00011000,
    0b00011000,
    0b01111110,
    0b00111100,
    0b00011000,
    0b00000000,
])

_fb_arrow_up = framebuf.FrameBuffer(bytearray(_ARROW_UP_8), 8, 8, framebuf.MONO_HLSB)
_fb_arrow_dn = framebuf.FrameBuffer(bytearray(_ARROW_DN_8), 8, 8, framebuf.MONO_HLSB)

def oled_draw_arrow(x, y, direction):
    if not oled:
        return
    if direction == "up":
        oled.blit(_fb_arrow_up, x, y)
    else:
        oled.blit(_fb_arrow_dn, x, y)

def oled_text_with_arrows(s, x, y):
    if not oled:
        return
    cx = x
    for ch in str(s):
        if ch == "▲":
            oled_draw_arrow(cx, y, "up")
            cx += 8
        elif ch == "▼":
            oled_draw_arrow(cx, y, "down")
            cx += 8
        else:
            oled.text(ch, cx, y)
            cx += 8

def oled_fill_rect_safe(x, y, w, h, c):
    if not oled:
        return
    if hasattr(oled, "fill_rect"):
        oled.fill_rect(x, y, w, h, c)
        return
    for yy in range(y, y + h):
        for xx in range(x, x + w):
            try:
                oled.pixel(xx, yy, c)
            except:
                pass

def _frame_bytes(w, h):
    pages = (h + 7) // 8
    return w * pages

def normalize_frames(anim_data, w, h):
    fb = _frame_bytes(w, h)

    if isinstance(anim_data, (list, tuple)):
        return anim_data

    if isinstance(anim_data, (bytes, bytearray, memoryview)):
        n = len(anim_data)
        if n == fb:
            return [anim_data]
        if n % fb == 0:
            mv = memoryview(anim_data)
            count = n // fb
            return [mv[i*fb:(i+1)*fb] for i in range(count)]
        raise ValueError("ANI buffer size does not match frame size")

    raise TypeError("Unsupported animation data type")

def oled_play_animation(oled, anim_data, w, h, x=0, y=0, fps=12, loop=False, clear=True):
    frames = normalize_frames(anim_data, w, h)
    if not frames:
        return

    fb_len = _frame_bytes(w, h)
    buf = bytearray(fb_len)
    fb = framebuf.FrameBuffer(buf, w, h, framebuf.MONO_VLSB)

    delay_ms = max(1, int(1000 // max(1, fps)))

    while True:
        for fr in frames:
            buf[:] = fr
            if clear:
                oled.fill(0)
            oled.blit(fb, x, y)
            oled.show()
            time.sleep_ms(delay_ms)

        if not loop:
            break

def _chunk_16(s: str):
    s = str(s)
    if not s:
        return [""]
    return [s[i:i+16] for i in range(0, len(s), 16)]

def oled_show_preset(mode_name, preset_name, pc, ch1, state="ON"):
    if not oled:
        return

    lines = []
    lines.append(mode_name[:16])

    wrapped = _chunk_16(preset_name)
    lines.append(wrapped[0][:16])
    lines.append(wrapped[1][:16] if len(wrapped) > 1 else "")

    lines.append(f"{state[:6]:6} PC:{pc:02d}"[:16])
    lines.append(f"CH:{ch1:02d}"[:16])

    oled.fill(0)
    y = 0
    for s in lines[:6]:
        oled_text_with_arrows(s, 0, y)
        y += 8
    oled.show()

def oled_show_realtime_status(momentary, layer_sw_val, mode, state, pc, pot_8bit, preset_name, ch1):
    if not oled:
        return

    l1 = f"MOM:{1 if momentary else 0} LY:{1 if layer_sw_val else 0}"[:16]
    l2 = f"MODE:{mode}"[:16]
    l3 = f"STATE:{state}"[:16]
    l4 = f"PC:{pc:02d}  CH:{ch1:02d}"[:16]
    l5 = f"POT:{pot_8bit:03d}"[:16]
    l6 = f"{str(preset_name)[:16]}"

    oled.fill(0)
    y = 0
    for s in (l1, l2, l3, l4, l5, l6):
        oled_text_with_arrows(s, 0, y)
        y += 8
    oled.show()

def oled_test_screen(timeout_cb=None):
    if not oled:
        print("OLED not available -> skip test screen")
        return

    if timeout_cb and timeout_cb():
        raise TimeoutError("OLED test timeout before start")

    oled.fill(0)
    oled.rect(0, 16, OLED_W, 12, 1)
    oled.show()

    for w in range(0, OLED_W - 2, 6):
        if timeout_cb and timeout_cb():
            raise TimeoutError("OLED test timeout during progress")
        oled_fill_rect_safe(1, 17, w, 10, 1)
        oled.show()
        time.sleep_ms(20)

    oled_clear()

def debounce_init(pin):
    v = pin.value()
    now = time.ticks_ms()
    return {"stable": v, "last_raw": v, "last_change_ms": now}

def debounce_update(pin, state, now_ms):
    raw = pin.value()
    if raw != state["last_raw"]:
        state["last_raw"] = raw
        state["last_change_ms"] = now_ms
    if time.ticks_diff(now_ms, state["last_change_ms"]) >= DEBOUNCE_MS:
        if state["stable"] != state["last_raw"]:
            state["stable"] = state["last_raw"]

def pressed_from_pullup(stable_raw):
    return stable_raw == 0

def adc_to_8bit(v_u16):
    return (v_u16 * 255 + 32767) // 65535

def build_presets_classic():
    active = []
    bypass = []

    for i, name in enumerate(WHAMMY_NAMES):
        active.append((f"{name}", 0 + i))
        bypass.append((f"{name}", 22 + i))

    active.append((f"DETUNE {DETUNE_NAMES[1]}", 10))
    bypass.append((f"DETUNE {DETUNE_NAMES[1]}", 32))

    active.append((f"DETUNE {DETUNE_NAMES[0]}", 11))
    bypass.append((f"DETUNE {DETUNE_NAMES[0]}", 33))

    for i, name in enumerate(HARMONY_NAMES):
        active.append((f"HARMONY {name}", 12 + i))
        bypass.append((f"HARMONY {name}", 34 + i))

    return active, bypass

def build_presets_chords():
    active = []
    bypass = []

    for i, name in enumerate(WHAMMY_NAMES):
        active.append((f"WHAMMY {name}", 42 + i))
        bypass.append((f"WHAMMY {name}", 63 + i))

    active.append((f"DETUNE {DETUNE_NAMES[1]}", 52))
    bypass.append((f"DETUNE {DETUNE_NAMES[1]}", 73))

    active.append((f"DETUNE {DETUNE_NAMES[0]}", 53))
    bypass.append((f"DETUNE {DETUNE_NAMES[0]}", 74))

    for i, name in enumerate(HARMONY_NAMES):
        active.append((f"HARMONY {name}", 54 + i))
        bypass.append((f"HARMONY {name}", 75 + i))

    return active, bypass

def make_bypass_lookup(bypass_list):
    d = {}
    for name, pc in bypass_list:
        d[name] = pc
    return d

def test_mode(mode_name, active_list, bypass_list, ch0):
    print(f"\n=== TEST MODE: {mode_name} | CH={ch0+1} ===")

    bypass_lookup = make_bypass_lookup(bypass_list)

    if oled:
        oled_show_preset(mode_name, "READY", 0, ch0 + 1, state="ON")
    time.sleep_ms(250)

    print_dbg_header(ch0 + 1)

    for name, pc_on in active_list:
        midi_pc(pc_on, ch0)
        print(fmt_dbg(mode_name[:DBG_COL_MODE], "ON", pc_on, ch0 + 1, name[:DBG_COL_NAME]))
        if oled:
            oled_show_preset(mode_name, name, pc_on, ch0 + 1, state="ON")
        time.sleep_ms(PC_STEP_DELAY_MS)

        if SEND_EFFECT_OFF_AFTER_ACTIVE and not TEST_DIRECT_MIDI_SWITCH:
            pc_off = bypass_lookup.get(name, None)
            if pc_off is not None:
                midi_pc(pc_off, ch0)
                print(fmt_dbg(mode_name[:DBG_COL_MODE], "OFF", pc_off, ch0 + 1, name[:DBG_COL_NAME]))
                if oled:
                    oled_show_preset(mode_name, name, pc_off, ch0 + 1, state="BYPASS")
                time.sleep_ms(EFFECT_OFF_DELAY_MS)

def run_all_tests(ch0):
    print("=== Whammy 5: FULL TEST (CLASSIC + CHORDS) ===")
    print(f"UART={MIDI_UART_ID} TX=GP{MIDI_TX_PIN} (TX-only) baud={MIDI_BAUD}")
    print(f"TEST_CHANNEL={ch0} (shown as CH={ch0+1})  PC_MINUS_ONE={PC_MINUS_ONE}")
    print(f"TEST_DIRECT_MIDI_SWITCH={TEST_DIRECT_MIDI_SWITCH}  (skip OFF in test)")
    print("Ctrl+C to stop.\n")

    if oled:
        oled_show_preset("Whammy 5", "FULL TEST", 0, ch0 + 1, state="ON")
        time.sleep_ms(600)

    classic_active, classic_bypass = build_presets_classic()
    chords_active, chords_bypass = build_presets_chords()

    test_mode("CLASSIC", classic_active, classic_bypass, ch0)
    time.sleep_ms(BETWEEN_MODES_MS)
    test_mode("CHORDS", chords_active, chords_bypass, ch0)

    print("\n=== TESTS FINISHED ===\n")
    if oled:
        oled_show_preset("TESTS", "FINISHED", 0, ch0 + 1, state="ON")
        time.sleep_ms(800)
        oled_clear()
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

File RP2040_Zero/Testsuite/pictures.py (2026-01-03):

# pictures.py
# Single images (MONO_VLSB)
# https://www.nexosoft-engineering.de/bitmap.html

START_W = 128
START_H = 64
START = bytes([
  # 128x64 MONO_VLSB = 128 * ceil(64/8) = 1024 bytes
  0xFF, 0xFF, 0xFF, 0xFF, 0xFF, 0xFF, 0xFF, 0x0F, 0x0F, 0x0F, 0x0F, 0x0F, 0x0F, 0x0F, 0x0F, 0x0F,
  0x0F, 0x0F, 0x0F, 0x0F, 0x0F, 0x0F, 0x0F, 0x0F, 0x0F, 0x03, 0x03, 0x83, 0xE3, 0xE3, 0xE3, 0x03,
  0x03, 0x03, 0x73, 0x7F, 0x3F, 0x07, 0x03, 0x03, 0xC3, 0xE3, 0xC3, 0x03, 0x03, 0x03, 0x03, 0x1F,
  0x1F, 0x1F, 0x1F, 0x1F, 0x1F, 0x1F, 0x1F, 0x1F, 0x1F, 0x1F, 0x1F, 0x1F, 0x1F, 0x1F, 0x1F, 0x1F,
  0x1F, 0x1F, 0x1F, 0x1F, 0x1F, 0x1F, 0x1F, 0x1F, 0x1F, 0x1F, 0x1F, 0x1F, 0x1F, 0x1F, 0x1F, 0x1F,
  0x1F, 0x1F, 0x1F, 0x1F, 0x1F, 0x1F, 0x1F, 0x1F, 0x1F, 0x1F, 0x1F, 0x1F, 0x1F, 0x1F, 0x1F, 0x1F,
  0x1F, 0x1F, 0x1F, 0x1F, 0x1F, 0x1F, 0x1F, 0x1F, 0x1F, 0x1F, 0x1F, 0x1F, 0x1F, 0x1F, 0x1F, 0x1F,
  0x1F, 0x1F, 0x1F, 0x1F, 0x1F, 0x1F, 0x1F, 0x1F, 0xFF, 0xFF, 0xFF, 0xFF, 0xFF, 0xFF, 0xFF, 0xFF,
  0xFF, 0xFF, 0xFF, 0xFF, 0xFF, 0xFF, 0x87, 0x80, 0x80, 0x80, 0x80, 0x87, 0x87, 0x87, 0x87, 0x07,
  0x07, 0x07, 0x7F, 0xFF, 0xFF, 0xF8, 0x00, 0x00, 0x00, 0x80, 0xF8, 0xFF, 0xFF, 0xFF, 0xFD, 0xE0,
  0x00, 0x00, 0x00, 0x00, 0x00, 0x80, 0xF0, 0xFE, 0x3F, 0x07, 0x06, 0x06, 0x06, 0x06, 0x06, 0x06,
  0x06, 0x06, 0x06, 0x06, 0x06, 0x06, 0x06, 0x06, 0x06, 0x06, 0x06, 0x06, 0x06, 0x06, 0x06, 0x06,
  0x06, 0x06, 0x06, 0x06, 0x06, 0x06, 0x06, 0x06, 0x06, 0x06, 0x06, 0x06, 0x06, 0x06, 0x06, 0x06,
  0x06, 0x06, 0x06, 0x06, 0x06, 0x06, 0x06, 0x06, 0x06, 0x06, 0x06, 0x06, 0x06, 0x06, 0x06, 0x06,
  0x06, 0x06, 0x06, 0x06, 0x06, 0x06, 0x06, 0x06, 0x06, 0x06, 0x06, 0x06, 0x06, 0x06, 0x06, 0x06,
  0x06, 0x06, 0x06, 0x86, 0x80, 0x80, 0x80, 0x80, 0xFF, 0xFF, 0xFF, 0xFF, 0xFF, 0xFF, 0xFF, 0xFF,
  0xFF, 0xFF, 0xFF, 0xFF, 0xFF, 0xFF, 0xFF, 0xFF, 0xFF, 0xFF, 0xFF, 0xFF, 0xFF, 0xFF, 0xFF, 0xE0,
  0x00, 0x00, 0x00, 0x7F, 0xFF, 0xFF, 0xFC, 0xC0, 0xFE, 0xFF, 0xFF, 0x0F, 0x03, 0x7F, 0xFF, 0xFF,
  0xFC, 0x00, 0x00, 0xE0, 0xFC, 0xFF, 0x1F, 0x01, 0x00, 0xFE, 0xFF, 0xCF, 0xC0, 0xC0, 0xC0, 0xC0,
  0xFF, 0xFF, 0x7F, 0x00, 0x00, 0x00, 0x00, 0xC3, 0xC3, 0xC3, 0xC3, 0xC3, 0xC7, 0xFF, 0xFF, 0x00,
  0x00, 0x00, 0x00, 0x01, 0xFF, 0xFF, 0x3F, 0x7C, 0xF0, 0xE0, 0x80, 0x00, 0x00, 0xE0, 0xFC, 0xFF,
  0x7F, 0xFF, 0xFF, 0xF8, 0x00, 0x00, 0x00, 0x00, 0x7F, 0xFF, 0xFF, 0x3E, 0xF8, 0xE0, 0x80, 0xF0,
  0xFF, 0x7F, 0xFF, 0xF8, 0x80, 0x00, 0x01, 0x1F, 0xFF, 0xF8, 0x80, 0xC0, 0xFC, 0x7F, 0x07, 0x00,
  0x00, 0xE0, 0xFC, 0xFF, 0xFF, 0xFF, 0xFF, 0xFF, 0xFF, 0xFF, 0xFF, 0xFF, 0xFF, 0xFF, 0xFF, 0xFF,
  0xFF, 0xFF, 0xFF, 0xFF, 0xFF, 0xFF, 0xFF, 0xFF, 0xFF, 0xFF, 0xFF, 0xFF, 0xFF, 0xFF, 0xFF, 0xFF,
  0xE0, 0x00, 0x00, 0x00, 0x3F, 0xFF, 0xFF, 0xFF, 0x7F, 0x07, 0x00, 0x00, 0x00, 0x00, 0x1F, 0xFF,
  0xFF, 0xFF, 0xFF, 0x3F, 0x07, 0x00, 0x00, 0x00, 0xFE, 0xFF, 0x1F, 0x01, 0x01, 0x01, 0x01, 0xE1,
  0xFF, 0xFF, 0x00, 0x00, 0x00, 0x80, 0xFE, 0xFF, 0xEF, 0xE1, 0xE1, 0xE1, 0xE1, 0xFF, 0xFF, 0xF8,
  0x00, 0x00, 0x00, 0x00, 0xFF, 0xFF, 0x00, 0x00, 0x01, 0x07, 0x0F, 0x3F, 0xFF, 0xFF, 0x1F, 0x03,
  0x00, 0x00, 0x1F, 0xFF, 0xFC, 0x00, 0x00, 0x00, 0x00, 0xFF, 0xFF, 0xF8, 0x00, 0x03, 0x07, 0x1F,
  0x0F, 0x00, 0x00, 0x0F, 0x1F, 0x08, 0x00, 0x00, 0x01, 0x03, 0xFF, 0xFF, 0xFF, 0x00, 0x00, 0x00,
  0x3F, 0xFF, 0xFF, 0xFF, 0xFF, 0xFF, 0xFF, 0xFF, 0xFF, 0xFF, 0xFF, 0xFF, 0xFF, 0xFF, 0xFF, 0xFF,
  0xFF, 0xFF, 0xFF, 0xFF, 0xFF, 0xFF, 0xFF, 0xFF, 0xFF, 0xFF, 0xFF, 0xFF, 0xFF, 0xFF, 0xFF, 0xFF,
  0xFF, 0xF0, 0xF0, 0xF0, 0xF0, 0xF0, 0xF0, 0xF0, 0xF0, 0xF0, 0xF8, 0xFE, 0xF0, 0xF0, 0xF0, 0xF0,
  0xF0, 0xF0, 0xF0, 0x10, 0x00, 0x00, 0x00, 0xC0, 0xC0, 0xC0, 0xC0, 0xC0, 0x80, 0x00, 0x00, 0x00,
  0x00, 0x00, 0x00, 0xC0, 0xC0, 0xC0, 0x00, 0x00, 0x00, 0x00, 0x00, 0xC0, 0xC0, 0xC0, 0xC0, 0xC0,
  0xC0, 0xC0, 0xC0, 0xC0, 0xC0, 0x00, 0x00, 0x00, 0x00, 0x80, 0xC0, 0xC0, 0xC0, 0xC0, 0xC0, 0xC0,
  0xC0, 0xC0, 0xC0, 0xC0, 0xC0, 0x80, 0x00, 0x00, 0x00, 0x00, 0x00, 0x40, 0xC0, 0xC0, 0xC4, 0xC4,
  0xC4, 0xC4, 0xC4, 0xC6, 0xC7, 0xC6, 0xC6, 0xC2, 0xC3, 0xC3, 0xC3, 0xC3, 0xC3, 0xC0, 0xC0, 0xC0,
  0xC0, 0xFF, 0xFF, 0xFF, 0xFF, 0xFF, 0xFF, 0xFF, 0xFF, 0xFF, 0xFF, 0xFF, 0xFF, 0xFF, 0xFF, 0xFF,
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
])
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

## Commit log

2025-12-25 Add warning about modification risks
    Added warning about potential device bricking and warranty loss.
2025-12-31 Update print statement from 'Hello' to 'Goodbye'
2026-01-03 Update print statement to say 'Goodbye World'
